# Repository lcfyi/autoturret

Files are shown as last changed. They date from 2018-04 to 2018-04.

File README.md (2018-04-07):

# autoturret

This project aims to leverage a Raspberry Pi to process an detect motion in a frame; this motion data is then sent to an Arduino where it will control two servos to point toward the motion.

The general flow of the system is as follows:
Flowchart

The most important thing to note from the diagram is that the serial connection is two-way, while the i2c connection is one-way slave to master. 

# Raspberry Pi Setup Notes

## Housekeeping
Expand filesystem

    sudo raspi-config

Check storage available

    df -h 

Install dependencies 

    sudo apt-get update && sudo apt-get upgrade 

## For video handling

    sudo apt-get install libjpeg-dev libtiff5-dev libjasper-dev libpng12-dev
    sudo apt-get install libavcodec-dev libavformat-dev libswscale-dev libv4l-dev
    sudo apt-get install libxvidcore-dev libx264-dev

## For the drawing and opencv stuff

    sudo apt-get install libgtk2.0-dev libgtk-3-dev
    sudo apt-get install libatlas-base-dev gfortran
    sudo apt-get install python-smbus python3-smbus python-dev python3-dev
    sudo apt-get install i2c-tools

## Additional packages that'll make things faster

    sudo pip install numpy
    sudo pip install imutils
    sudo pip install serial
    sudo pip install smbus

## The actual important bit

    sudo apt-get install python-opencv

## Make it easier to find the pi 

    sudo apt-get install samba
    
   This allows ping raspberrypi to respond on Windows.

## Auto run at start

    sudo nano /etc/profile

Add this snippet to the bottom:

    sudo python ~/Desktop/main.py &

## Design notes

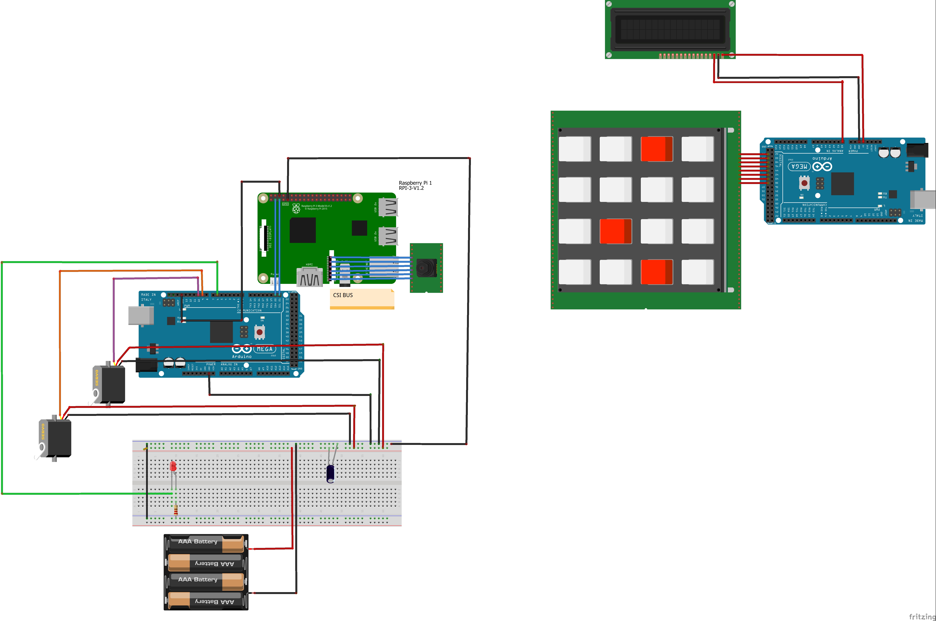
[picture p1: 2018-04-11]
assets/Turret_Hardware.jpg

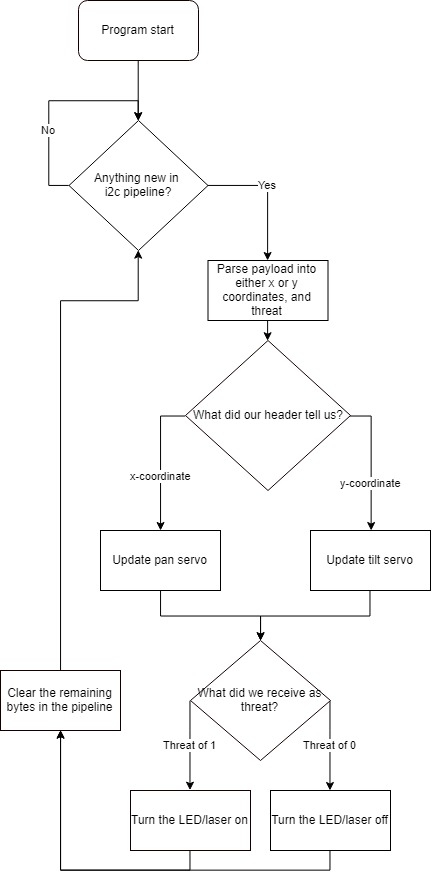
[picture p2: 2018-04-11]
assets/SERVO.jpg

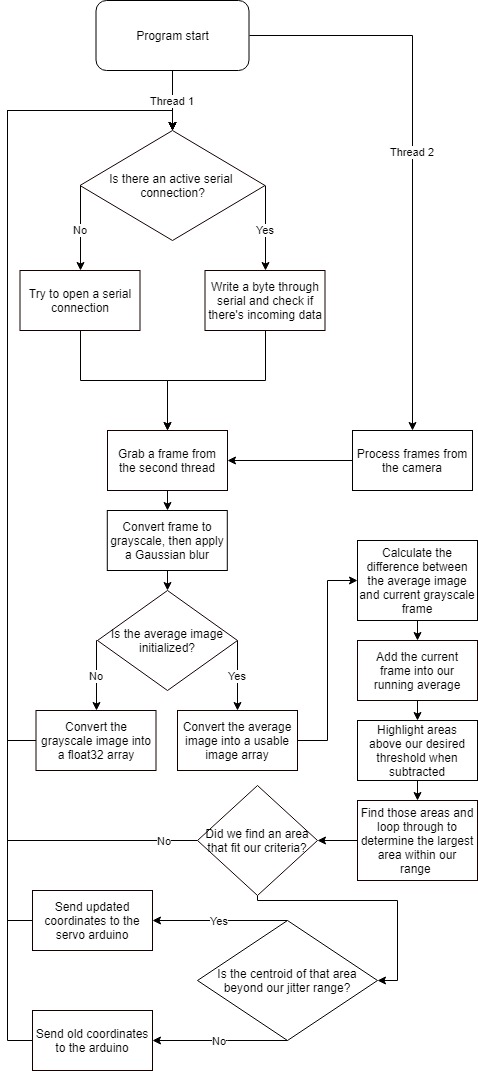
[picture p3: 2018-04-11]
assets/PI_CHART.jpg

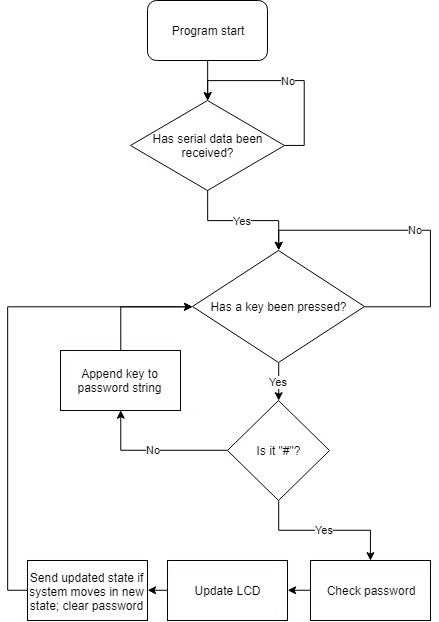
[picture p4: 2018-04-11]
assets/AUTH_MODULE.jpg

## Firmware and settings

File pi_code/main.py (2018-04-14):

#!/usr/bin/python
from imutils.video.pivideostream import PiVideoStream
import numpy
import math
import time
import cv2
import smbus
import serial
import serial.tools.list_ports as lp
import argparse

# -----------------------------------------------------------------------
# modify globals to tailor to different setups
# -----------------------------------------------------------------------

address = 0x08 # address of the Arduino
arduinoSerialName = "ACM"

gassianBlurAmount = 11
accumulateWeight = 0.5
acceptableDelta = 7
dilateIterations = 2

minArea = 500
maxArea = 9000

xJitterAmount = 8
yJitterAmount = 6

# -----------------------------------------------------------------------
# other variables to set up the rest of the code
# -----------------------------------------------------------------------

parser = argparse.ArgumentParser()
parser.add_argument("--debug", help="this will print out status messages", action="store_true")
args = parser.parse_args()
debugMode = args.debug

bus = smbus.SMBus(1)

vs = PiVideoStream().start() # starting our video stream
time.sleep(1)

averageImage = None # average frame data
mode = 0 # default mode for the turret
ser = None # serial object
threat = 0 # default threat of 0
lastX = 0
lastW = 0
lastY = 0
lastH = 0
written = False
changed = True

# -----------------------------------------------------------------------
# communicate with the Pi through i2c
# mode 0 for coordinate sending, mode 1 to disable turret
# threat 0 laser is off, threat 1 laser is on
# -----------------------------------------------------------------------
def sendToArduino(mode, threat, x_coord, y_coord):
  global written
  try: # try block to catch i2c errors without aborting code
    if mode is 0:
      written = False
      data = [threat]
      # turn numbers into strings
      for n in str(x_coord):
        data.append(ord(n))
      # send each char byte to arduino
      bus.write_i2c_block_data(address, 0, data)
      data = [threat]
      for n in str(y_coord):
        data.append(ord(n))
      bus.write_i2c_block_data(address, 1, data)
      data = [threat]
      if debugMode:
        print("[NOTE] Writing x: {0}, y: {1}".format(x_coord, y_coord))
    elif mode is 1:
      if not written:
        bus.write_i2c_block_data(address, 2, [threat])
        if debugMode:
          print("[NOTE] Turret disabled")
        written = True
  except IOError:
    if debugMode:
      print("[NOTE] i2c error")
    pass

# -----------------------------------------------------------------------
# monitor serial input and update state if there are any changes
# -----------------------------------------------------------------------
def readSerial():
  try:
    # global variables
    global mode
    global threat
    global ser
    global written
    ser.write(str(1))
    if ser.in_waiting:
      written = False
      mode_and_threat = int(ser.readline())
      threat = mode_and_threat % 10
      mode = int(math.floor(mode_and_threat / 10)) % 10
      if debugMode:
        print("[NOTE] Mode updated to {0}".format(mode))
        print("[NOTE] Threat updated to {0}".format(threat))
      # reset laser pointer
      if mode is 1:
        sendToArduino(mode, threat, None, None)
  except IOError:
    if debugMode:
      print("[NOTE] Serial error")
    ser = None
    pass

# -----------------------------------------------------------------------
# the code starts at this point; follow each step line by line
# -----------------------------------------------------------------------
while True:
  # establish serial communication before system starts or if it gets lost
  if ser is None:
    arduinoPorts = [p.device for p in lp.comports() if arduinoSerialName in p.description]
    try:
      ser = serial.Serial(arduinoPorts[0], 9600, timeout=0)
      # wait for the Arduino to power up
      time.sleep(4)
    except:
      if debugMode:
        print("[NOTE] Serial error")
      pass
  else:
    readSerial()

  # grab a frame from our threaded pivideostream
  f = vs.read()

  # convert the frame to grayscale
  gray = cv2.cvtColor(f, cv2.COLOR_BGR2GRAY)
  gray = cv2.GaussianBlur(gray, (gassianBlurAmount, gassianBlurAmount), 0)

  # initiate the average
  if averageImage is None:
    averageImage = numpy.float32(gray)
    continue

  # turn our average image into something usable 
  frameComp = cv2.convertScaleAbs(averageImage)

  # calculate the difference in the frame and average image
  frameDelta = cv2.absdiff(frameComp, gray)

  # add our frame to the running average
  cv2.accumulateWeighted(gray, averageImage, accumulateWeight)

  # find the areas that are above our threshold 
  threshold = cv2.threshold(frameDelta, acceptableDelta, 255, cv2.THRESH_BINARY)[1]

  # fill in the holes and find the contours
  threshold = cv2.dilate(threshold, None, iterations=dilateIterations)
  contours = cv2.findContours(threshold.copy(), cv2.RETR_EXTERNAL, cv2.CHAIN_APPROX_SIMPLE)[0]

  # find the biggest contour within our range
  temp = None
  for c in contours:
    if cv2.contourArea(c) < minArea or cv2.contourArea(c) > maxArea:
      continue
    elif temp is None or cv2.contourArea(c) > cv2.contourArea(temp):
      temp = c

  # draw boxes around our area of interest, taking into account our jitter reduction
  if temp is not None:
    (x, y, w, h) = cv2.boundingRect(temp)
    if abs(lastX - (x + w/2)) > lastW/xJitterAmount:
      lastX = int(x + w/2)
      lastW = w
      changed = True
    if abs(lastY - (y + h/3)) > lastH/yJitterAmount:
      lastY = int(y + h/3)
      lastH = h
      changed = True
    if debugMode:
      cv2.rectangle(f, (x, y), (x + w, y + h), (0, 255, 0), 1)
    if changed:
      sendToArduino(mode, threat, lastX, lastY)
      changed = False

  # draw things for our debug mode
  if debugMode:
    cv2.circle(f, (lastX, lastY), 3, (0, 255, 0), 2)
    cv2.imshow("Frames", f)
    cv2.imshow("Thresh", threshold)
    cv2.imshow("frame delta", frameDelta)
    cv2.imshow("avg", frameComp)
    cv2.waitKey(1)

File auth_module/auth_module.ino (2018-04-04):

#include "Keypad.h"
#include <stdlib.h>
#include <serLCD.h>
#include <SoftwareSerial.h>

// STATES:
// MODE 0 - turret tracking (armed)
// MODE 1 - turret disabled (disarmed)

// THREAT 0 - laser off (unauthenticated, still has attempts)
// THREAT 1 - laser on (unauthenticated, no attempts)

// ---------------- STATE 0
// ARMED -- TRIES:5
// Code: 
// ---------------- STATE 1
// ATTEMPTS REACHED
// LOCKDOWN MODE ON
// ---------------- STATE 2
// DISARMED -- arm
// system with 000

// -----------------------------------------------------------------------
// modify globals to tailor to different and setups
// -----------------------------------------------------------------------

// KEYPAD: these go in order as listed from 8 --> 1
const int R0 = A0;
const int R1 = A1;
const int R2 = A2;
const int R3 = A3;
const int C0 = A4; 
const int C1 = A5;
const int C2 = A6;
const int C3 = A7;
const byte ROWS = 4;
const byte COLS = 4;

const int ledPin = 11;

// PASSWORD (max attempts: 9)
const int NUM_ATTEMPTS = 3;
const int NUM_PASSWORDS = 5;
String database[NUM_PASSWORDS] = {"1234", "6969", "420", "3258", "9993"};
const String OVERRIDE_CODE = "0000";

// LCD
const int LCDPin = 14;

// -----------------------------------------------------------------------

// keymap and keypad rows
char keymap[ROWS][COLS] =
{
{'1', '2', '3', 'A'},
{'4', '5', '6', 'B'},
{'7', '8', '9', 'C'},
{'*', '0', '#', 'D'}
};
byte rPins[ROWS]= {R0, R1, R2, R3};
byte cPins[COLS]= {C0, C1, C2, C3};
Keypad kpd = Keypad(makeKeymap(keymap), rPins, cPins, ROWS, COLS);

// state variables
int state = 0;
int lastState = state;

// LCD setup 
serLCD lcd(LCDPin);

// function declarations
void sendState(int state);
void updateLCD(int state = -1);
int checkPassword();
void flushBuffer();

// password and attempt tracking
String password = "";
char lastKey = NO_KEY;
int numAttempts = NUM_ATTEMPTS;

void setup()
{
  pinMode(ledPin, OUTPUT);
  Serial.begin(9600);
  bool printed = false;
  delay(1000);
  while(Serial.available() == 0)
  {
    if(!printed)
    {
      lcd.clear();
      lcd.print("Waiting..");
    }
    printed = true;
  }
  updateLCD(0);
}

void loop()
{
  flushBuffer();
  lastKey = kpd.getKey();
  if(lastKey != NO_KEY)
  {
    if(state == 0) updateLCD();
    if(lastKey == '#')
    {
      switch(checkPassword())
      {
        case 0:
          state = 0;
          digitalWrite(ledPin, LOW);
          updateLCD(state);
          sendState(state);
          lastState = state;
          break;
        case 1:
          digitalWrite(ledPin, HIGH);
          state = 1;
          updateLCD(state);
          sendState(state);
          lastState = state;
          break;
        case 2:
          digitalWrite(ledPin, LOW);
          state = 2;
          updateLCD(state);
          sendState(state);
          lastState = state;
          break;
      }
    } else password += lastKey;
  }
}

void sendState(int s)
{
  if(s != lastState)
  {
    switch(s)
    {
      // MODE 0 THREAT 0
      case 0:
        Serial.print("00");
        return;
      // MODE 0 THREAT 1
      case 1:
        Serial.print("01");
        return;
      // MODE 1 THREAT 0 (threat doesn't matter when turret is disabled)
      case 2:
        Serial.print("10");
        return;
    }
  }
}

void updateLCD(int s)
{
  switch(s)
  {
    case 0:
      lcd.clear();
      lcd.print("ARMED -- TRIES:" + String(numAttempts));
      lcd.print("Code: ");
      return;
    case 1: 
      lcd.clear();
      lcd.print("ATTEMPTS REACHED");
      lcd.print("LOCKDOWN MODE ON");
      return;
    case 2:
      lcd.clear();
      lcd.print("DISARMED -- arm ");
      lcd.print("system with 0000");
      return;
    default:
      lcd.print(lastKey);
      return;
  }
}

// only called when # is pressed 
int checkPassword() {
  if(state == 0) 
  {
    numAttempts -= 1;
    for(int i = 0; i < NUM_PASSWORDS; i++) 
    {
      if(database[i] == password)
      {
        password = "";
        numAttempts = NUM_ATTEMPTS;
        return 2;
      }
    }
    if(numAttempts == 0)
    {
      password = "";
      return 1;
    }
    password = "";
    return state;
  }
  else if(state == 1)
  {
    if(password == OVERRIDE_CODE) 
    {
      password = "";
      numAttempts = NUM_ATTEMPTS;
      return 0;
    }
    password = "";
    return state;
  }
  else if(state == 2)
  {
    if(password == OVERRIDE_CODE)
    {
      password = "";
      numAttempts = NUM_ATTEMPTS;
      return 0;
    }
    password = "";
    return state;
  }
}

void flushBuffer()
{
  while(Serial.available())
  {
    Serial.read();
  }
}

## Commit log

2018-03-31 Pan support, calibrated
2018-04-01 Updated keypad.ino
    Included new functions:
    -turnOff();
    -finalState();
    -lcdPressed(char key);
    -lcdDisp(int disp);
    -currentState(char code);
    included new variables:
    laser
    stateToPi
    edited the following functions:
    readKey();
    void loop();
    removed functions:
    overrideState();
    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
2018-04-01 Additional serial error handling
    [main.py]
2018-04-02 LED status support
2018-04-03 Added flowchart
2018-04-03 Flowchart round 2
2018-04-03 Flowchart round 3
2018-04-04 More responsive behaviour wrt. disabling turret laser
2018-04-04 Fixed Arduino Mega bug where serial will come out of sync
    [auth_module.ino, main.py]
2018-04-04 Untested, but removed i2c delay
2018-04-05 More debugging prompts and more responsive disabling of laser
2018-04-07 More instructions in case Pi goes kaput
2018-04-09 Add files via upload
    Included are the following:
    - A completed flow diagram of the PI_CODE
    - A XML file of the flow diagram for further editing in the future
2018-04-09 Add files via upload
    Included is are the following:
    - A flow diagram of the AUTH_MODULE
    - A XML file of the flow diagram for future editing.
2018-04-09 Add files via upload
    Included is the following:
    - A flow diagram for the turret_module
    - A XML file for future editing for the flow diagram
2018-04-10 Added LCD library in case
2018-04-11 Add files via upload
    Revised PI_CHART. Changes are as follows:
    Removed " Wait for arduino to power up " and included a decision diamond " Is there an error?" with "print out serial error" added for yes case.
2018-04-11 Add files via upload
    Revised Servo png and xml. Changes are as follows:
    - Decision diamond " Anything new in i2c pipeline?" no case leads back to decision diamond "Anything new in i2cpipeline?".
    - Removed "Continue looping through recieved bytes", "write that angle to our servo."
    - Included "translate our coordinate to a servo angle and write to our servo."
2018-04-11 Add files via upload
    Revision to auth_module.png and auth_module.xml are as follows:
    - Moved no case in " Has the key been pressed?" back to decision diamond " Has the key been pressed"?
    - Moved arrow from " Arduino sends state to pi unless it's the same state previously" on the decision diamond " Has the key been pressed? " below to make room for the first change.
    - Included yes case for decision diamond " Has the key been pressed?"
2018-04-11 Add files via upload
    Converted to JPEG to reduce issues with export.
    Updated PI_CHART.xml and PI_CHART.JPG to remove " Ping to arduino"
2018-04-11 Add files via upload
    Uploaded the hardware fritzing as well as a jpeg
    [Turret_Hardware.fzz]
2018-04-11 Updated flowcharts
2018-04-11 More changes to the flowchart logic
2018-04-14 Reduced i2c spam
2018-04-14 Further calibration of the turret
